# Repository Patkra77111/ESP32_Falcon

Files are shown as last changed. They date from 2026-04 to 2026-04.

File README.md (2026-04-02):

# ESP32_Falcon
Jest to customowa płytka deweloperska oparta na module ESP32-S3, była ona inspirowana designem STM32 Nucleo. Jest to projekt rekrutacyjny do koła naukowego FALCON na Politechnice Wrocławskiej. Został on całkowicie wykonany w KiCad.

## Specyfikacja
**Mikrokontroler:** ESP32-S3-WROOM-1.
* **Komunikacja i Zasilanie:** Złącze USB-C z układem zabezpieczającym ESD.
* **Czujniki:** Zintegrowany czujnik IMU BMI270 podłączony przez I2C.
* **Rozszerzalność:** Wyprowadzenia sygnałowe na złączach goldpin w układzie Nucleo.

### 1. Schemat 
schemat

### 2. Layout PCB
PCB

### 3. Model 3D
3D

## Główne Decyzje Projektowe i Zasady EMC
1. **Prowadzenie sygnałów USB (D+/D-):** Linie danych z USB-C zostały poprowadzone jako para różnicowa na jednej warstwie, bez użycia przelotek, w celu zachowania spójności impedancji.
2. **Zachowanie strefy Keepout dla anteny:** Moduł ESP32-S3 został umieszczony na krawędzi płytki, a jego antena znajduje się całkowicie poza obrysem miedzi i laminatu, aby uniknąć tłumienia sygnału.
3. **Dystrybucja Zasilania i Decoupling:** Ścieżki zasilające mają odpowiednią grubość (0.4mm - 0.5mm) i są prowadzone bezpośrednio do głównych odbiorników. Kondensatory filtrujące zostały umieszczone w bezpośrednim sąsiedztwie pinów zasilających ESP32 oraz BMI270.
4. **Wylewki GND (Copper Pours):** Wylewki masy na obu stronach laminatu. Połacie masy zostały połączone za pomocą przelotek.

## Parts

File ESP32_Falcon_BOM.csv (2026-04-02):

Reference | Qty | Value | DNP | Exclude from BOM | Exclude from Board | Footprint | Datasheet
BOOT1,EN1,USER_BUTTON1 | 3 | SW_Push |  |  |  | Button_Switch_SMD:SW_Push_1TS009xxxx-xxxx-xxxx_6x6x5mm | ~
C2,C3 | 2 | 0.1u |  |  |  | Capacitor_SMD:C_0805_2012Metric_Pad1.18x1.45mm_HandSolder | ~
C2_tantalum1,C3_tantalum1 | 2 | 22u |  |  |  | Capacitor_SMD:C_0805_2012Metric_Pad1.18x1.45mm_HandSolder | ~
C4 | 1 | 1u |  |  |  | Capacitor_SMD:C_0805_2012Metric_Pad1.18x1.45mm_HandSolder | ~
D1,D2 | 2 | LED |  |  |  | LED_SMD:LED_0805_2012Metric_Pad1.15x1.40mm_HandSolder | ~
F2 | 1 | 1A |  |  |  | Fuse:Fuse_1206_3216Metric_Pad1.42x1.75mm_HandSolder | ~
FB2 | 1 | BLM21PG221 |  |  |  | Inductor_SMD:L_0805_2012Metric_Pad1.05x1.20mm_HandSolder | ~
J1 | 1 | USB_C_Receptacle_USB2.0_16P |  |  |  | Connector_USB:USB_C_Receptacle_XKB_U262-16XN-4BVC11 | https://www.usb.org/sites/default/files/documents/usb_type-c.zip
J2,J3 | 2 | Conn_01x15_Pin |  |  |  | Connector_PinHeader_2.54mm:PinHeader_1x15_P2.54mm_Vertical | ~
R1,R2 | 2 | 5k1 |  |  |  | Resistor_SMD:R_0805_2012Metric_Pad1.20x1.40mm_HandSolder | ~
R3,R6,R9 | 3 | 10k |  |  |  | Resistor_SMD:R_0805_2012Metric_Pad1.20x1.40mm_HandSolder | ~
R4,R5 | 2 | 1k |  |  |  | Resistor_SMD:R_0805_2012Metric_Pad1.20x1.40mm_HandSolder | ~
R7,R8 | 2 | 4.7k |  |  |  | Resistor_SMD:R_0805_2012Metric_Pad1.20x1.40mm_HandSolder | ~
U1 | 1 | ESP32-S3-WROOM-1 |  |  |  | RF_Module:ESP32-S3-WROOM-1 | https://www.espressif.com/sites/default/files/documentation/esp32-s3-wroom-1_wroom-1u_datasheet_en.pdf
U2 | 1 | USBLC6-2SC6 |  |  |  | Package_TO_SOT_SMD:SOT-23-6 | https://www.st.com/resource/en/datasheet/usblc6-2.pdf
U3 | 1 | AMS1117-3.3 |  |  |  | Package_TO_SOT_SMD:SOT-223-3_TabPin2 | http://www.advanced-monolithic.com/pdf/ds1117.pdf
U4 | 1 | BMI270 |  |  |  | footprints:BMI270_BOS | BMI270

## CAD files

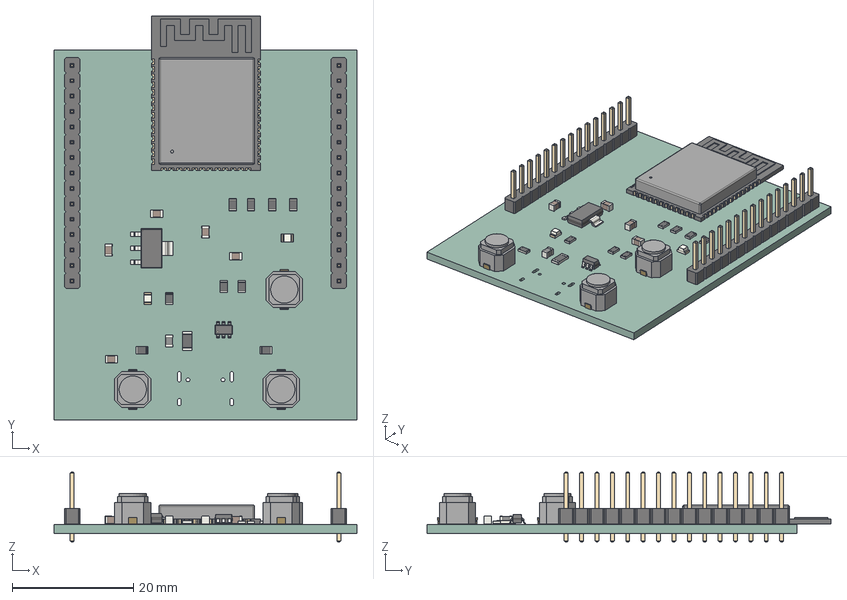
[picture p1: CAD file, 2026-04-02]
ESP32_Falcon.step
50.0 x 66.6 x 11.5 mm
SOT-23-6
PinHeader_1x15_P2.54mm_Vertical x 2
Fuse_1206_3216Metric
C_0805_2012Metric x 5
ESP32-S3-WROOM-1
R_0805_2012Metric x 9
pin_1 x 3
pin_2 x 3
SOT-223
LED_0805_2012Metric x 2
L_0805_2012Metric
ESP32_Falcon_PCB

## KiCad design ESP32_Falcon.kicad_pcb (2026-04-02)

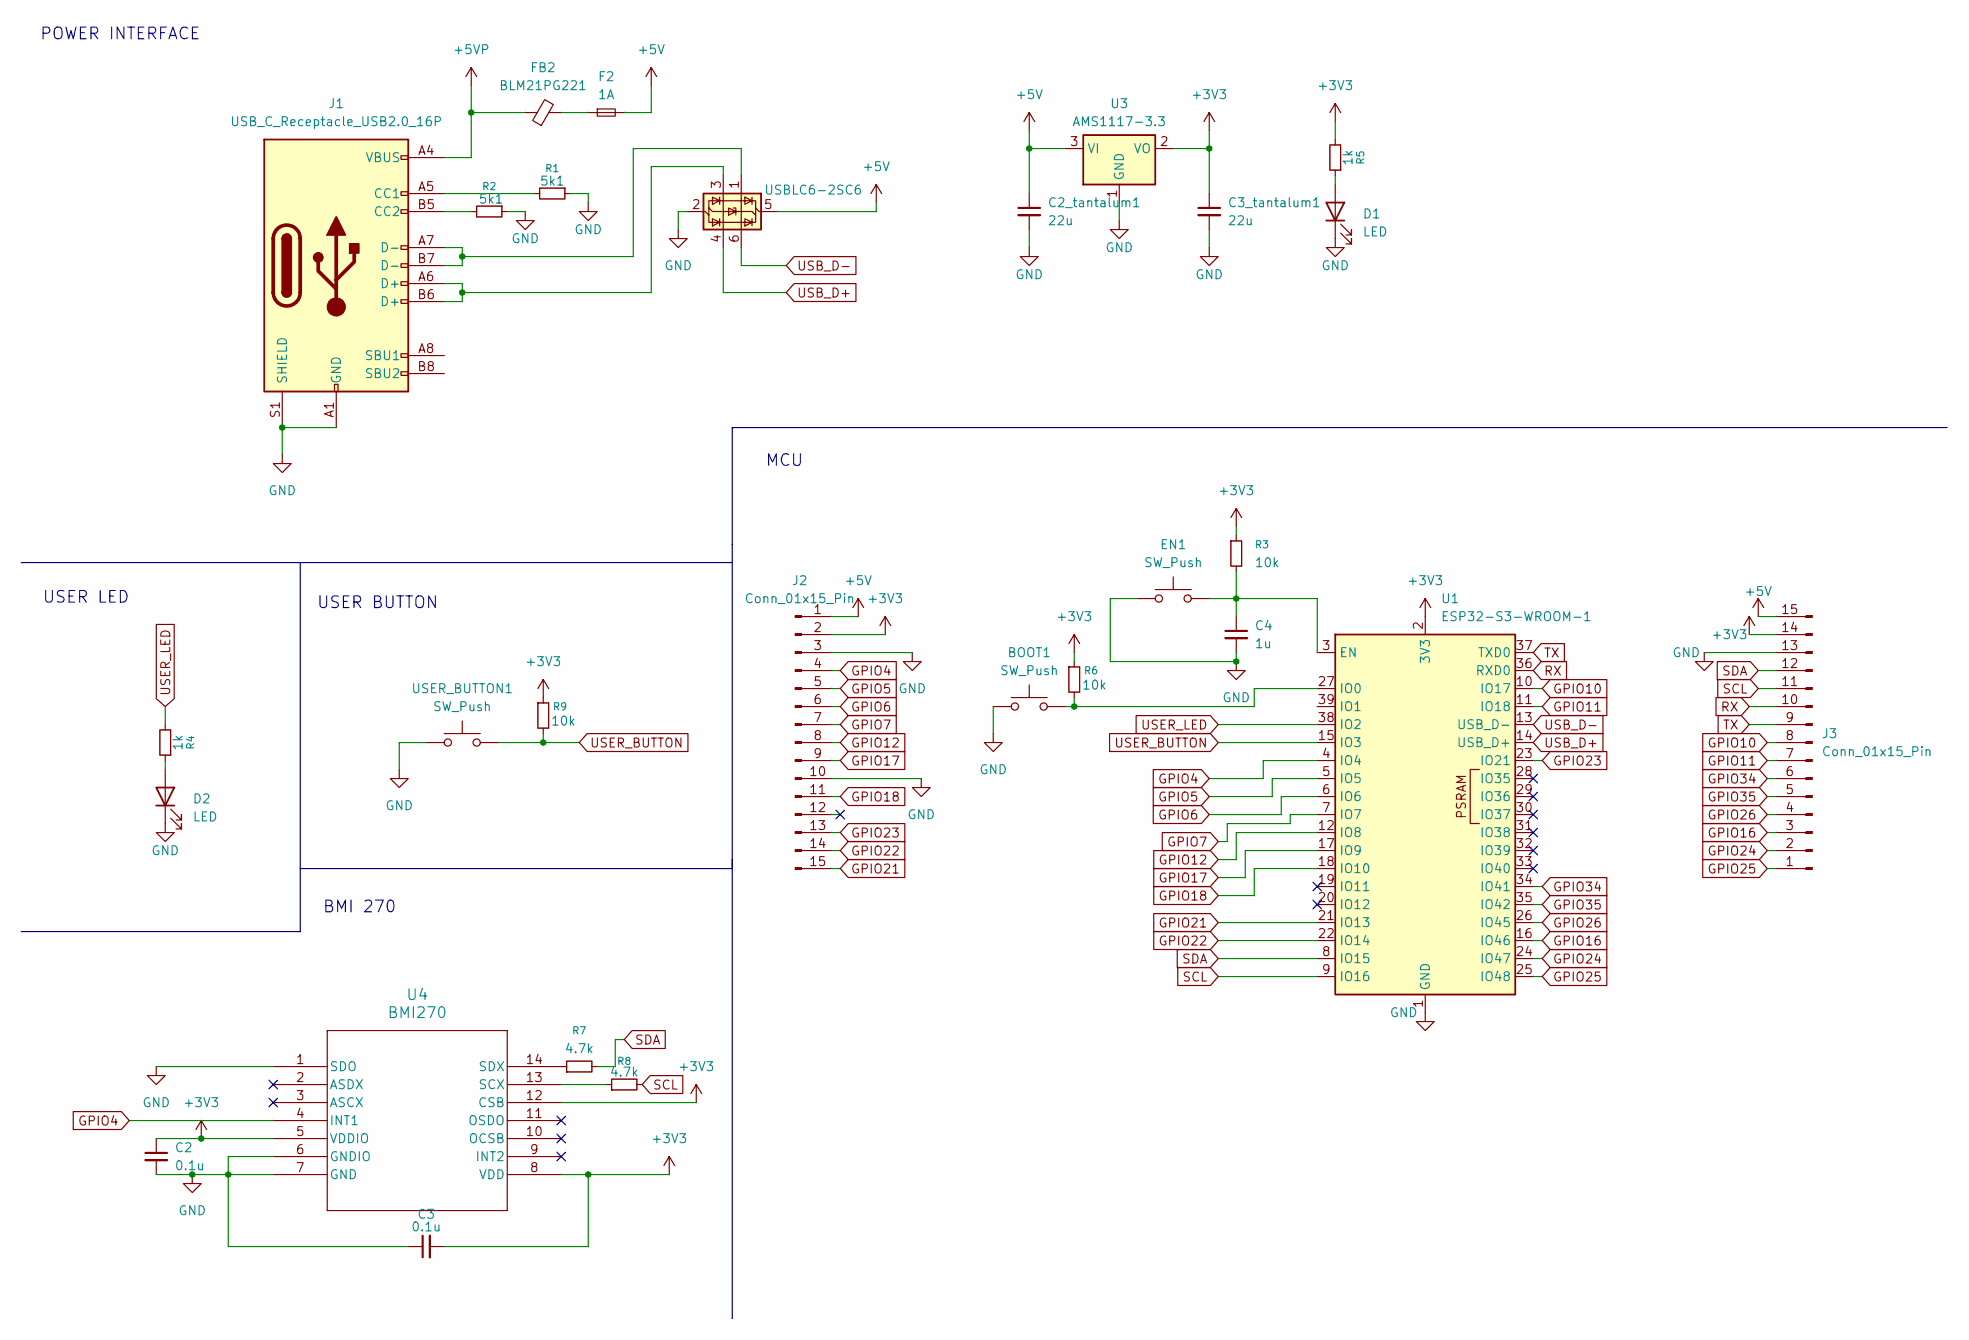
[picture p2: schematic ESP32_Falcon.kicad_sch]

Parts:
BOOT1: SW_Push; SW_Push_1TS009xxxx-xxxx-xxxx_6x6x5mm
C2, C3: 0.1u; C_0805_2012Metric_Pad1.18x1.45mm_HandSolder
C2_tantalum1, C3_tantalum1: 22u; C_0805_2012Metric_Pad1.18x1.45mm_HandSolder
C4: 1u; C_0805_2012Metric_Pad1.18x1.45mm_HandSolder
D1, D2: LED; LED_0805_2012Metric_Pad1.15x1.40mm_HandSolder
EN1: SW_Push; SW_Push_1TS009xxxx-xxxx-xxxx_6x6x5mm
F2: 1A; Fuse_1206_3216Metric_Pad1.42x1.75mm_HandSolder
FB2: BLM21PG221; L_0805_2012Metric_Pad1.05x1.20mm_HandSolder
J1: USB_C_Receptacle_USB2.0_16P; USB_C_Receptacle_XKB_U262-16XN-4BVC11
J2, J3: Conn_01x15_Pin; PinHeader_1x15_P2.54mm_Vertical
R1, R2: 5k1; R_0805_2012Metric_Pad1.20x1.40mm_HandSolder
R3, R6, R9: 10k; R_0805_2012Metric_Pad1.20x1.40mm_HandSolder
R4, R5: 1k; R_0805_2012Metric_Pad1.20x1.40mm_HandSolder
R7, R8: 4.7k; R_0805_2012Metric_Pad1.20x1.40mm_HandSolder
U1: ESP32-S3-WROOM-1
U2: USBLC6-2SC6; SOT-23-6
U3: AMS1117-3.3; SOT-223-3_TabPin2
U4: BMI270; BMI270_BOS
USER_BUTTON1: SW_Push; SW_Push_1TS009xxxx-xxxx-xxxx_6x6x5mm

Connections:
+3V3: C2.1, C3.2, C3_tantalum1.1, J2.2, J3.14, R3.1, R5.2, R6.1, R9.1, U1.2 (3V3), U3.2 (VO), U4.5 (VDDIO), U4.8 (VDD), U4.12 (CSB); also elsewhere on the board
+5V: C2_tantalum1.1, F2.2, J2.1, J3.15, U2.5 (VBUS), U3.3 (VI); also elsewhere on the board
+5VP: FB2.1, J1.A4 (VBUS), J1.A9 (VBUS), J1.B4 (VBUS), J1.B9 (VBUS)
GND: BOOT1.1, C2.2, C2_tantalum1.2, C3.1, C3_tantalum1.2, C4.2, D1.1 (K), D2.1 (K), EN1.1, J1.A1 (GND), J1.A12 (GND), J1.B1 (GND), J1.B12 (GND), J1.S1 (SHIELD), J2.3, J2.10, J3.13, R1.1, R2.1, U1.1 (GND), U1.40 (GND), U1.41 (GND), U2.2 (GND), U3.1 (GND), U4.1 (SDO), U4.6 (GNDIO), U4.7 (GND), USER_BUTTON1.1; also elsewhere on the board
GPIO4: J2.4, U1.4 (IO4), U4.4 (INT1)
GPIO5: J2.5, U1.5 (IO5)
GPIO6: J2.6, U1.6 (IO6)
GPIO7: J2.7, U1.7 (IO7)
GPIO10: J3.8, U1.10 (IO17)
GPIO11: J3.7, U1.11 (IO18)
GPIO12: J2.8, U1.12 (IO8)
GPIO16: J3.3, U1.16 (IO46)
GPIO17: J2.9, U1.17 (IO9)
GPIO18: J2.11, U1.18 (IO10)
GPIO21: J2.15, U1.21 (IO13)
GPIO22: J2.14, U1.22 (IO14)
GPIO23: J2.13, U1.23 (IO21)
GPIO24: J3.2, U1.24 (IO47)
GPIO25: J3.1, U1.25 (IO48)
GPIO26: J3.4, U1.26 (IO45)
GPIO34: J3.6, U1.34 (IO41)
GPIO35: J3.5, U1.35 (IO42)
unnamed: D1.2 (A), R5.1
unnamed: D2.2 (A), R4.1
unnamed: F2.1, FB2.2
unnamed: J1.A5 (CC1), R1.2
unnamed: J1.B5 (CC2), R2.2
unnamed: J1.A6 (D+), J1.B6 (D+), U2.3 (I/O2)
unnamed: J1.A7 (D-), J1.B7 (D-), U2.1 (I/O1)
unnamed: C4.1, EN1.2, R3.2, U1.3 (EN)
unnamed: BOOT1.2, R6.2, U1.27 (IO0)
unnamed: R8.1, U4.13 (SCX)
unnamed: R7.1, U4.14 (SDX)
RX: J3.10, U1.36 (RXD0)
SCL: J3.11, R8.2, U1.9 (IO16)
SDA: J3.12, R7.2, U1.8 (IO15)
TX: J3.9, U1.37 (TXD0)
USB_D+: U1.14 (USB_D+), U2.4 (I/O2)
USB_D-: U1.13 (USB_D-), U2.6 (I/O1)
USER_BUTTON: R9.2, U1.15 (IO3), USER_BUTTON1.2
USER_LED: R4.2, U1.38 (IO2)

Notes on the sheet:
BMI 270
USER LED
MCU
POWER INTERFACE
USER BUTTON

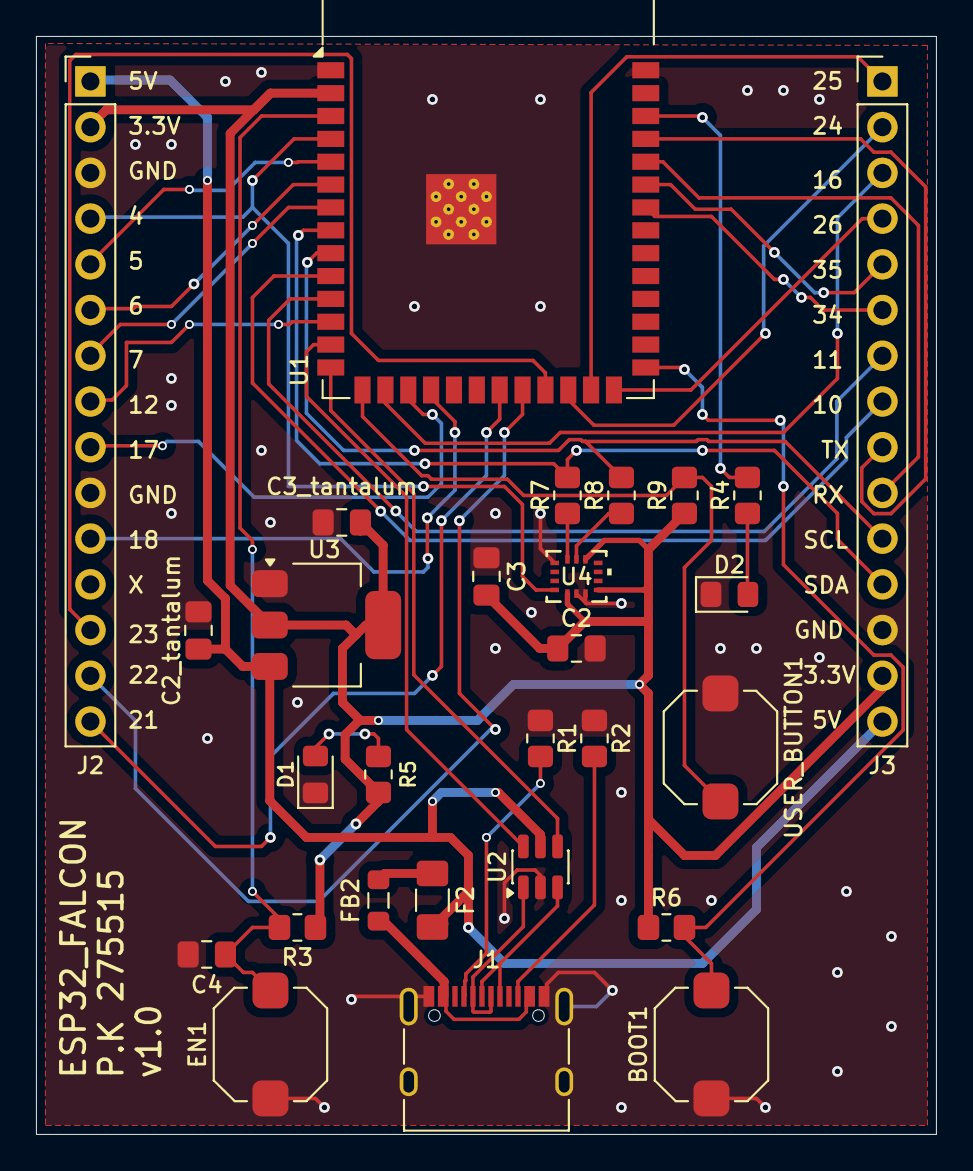
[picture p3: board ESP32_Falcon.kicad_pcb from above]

Board: 2 copper layers, 50.0 x 61.0 mm, 28 parts (0 on the bottom side), 41 nets.

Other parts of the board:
C2_tantalum, C3_tantalum: 22u; C_0805_2012Metric_Pad1.18x1.45mm_HandSolder

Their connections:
+3V3: C3_tantalum.1; also elsewhere on the board
+5V: C2_tantalum.1; also elsewhere on the board
GND: C2_tantalum.2, C3_tantalum.2; also elsewhere on the board

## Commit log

2026-03-28 Początek projektu, rozpoczęcie sekcji zasilania
    [ESP32_Falcon.kicad_pcb, ESP32_Falcon.kicad_sch]
2026-03-31 Praktycznie skonczony schematic
    [ESP32_Falcon.kicad_sch]
2026-03-31 Poczatek PCB
    [ESP32_Falcon.kicad_pcb, ESP32_Falcon.kicad_sch]
2026-04-01 Podlaczone glowne sciezki
    [ESP32_Falcon.kicad_pcb]
2026-04-02 skończony projekt
    [ESP32_Falcon-B_Cu.gbr, ESP32_Falcon-B_Mask.gbr, ESP32_Falcon-B_Paste.gbr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]
